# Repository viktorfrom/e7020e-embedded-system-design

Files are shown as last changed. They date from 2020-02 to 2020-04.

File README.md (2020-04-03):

# E7020E Embedded System Design
Project designed and written in Rust in conjunction with the E7020E Embedded System Design course at Luleå University of Technology. 



## Project description
The purpose of this project is to create a breathalyzer to estimate the blood alchohol content (BAC) in a person's breath. 
To do this a prototype PCB will be designed connected to an alchohol sensor, a button to start the breathalyzer and a small display to show the alchohol permille detected. Over LoRa this device will also alert a ThinkBoard server that this user's breath contains too much alchohol, i.e. they are about to pass out. 

The goal is to package this is in a simple and safe to use way for users to interact with. The data that is sent to the ThinkBoard server could be seen as sensitive data and would be ideal to encrypt it before transmitting it. 

### Limitations
There is no sure way to calibrate this device as the project team does not have access to a real industry-grade breathalyzer. Thus this device can only very roughly estimate the BAC of a person's breath and SHOULD NOT be trusted in any serious situation where it is critical to know the real BAC.

## Components / shopping list
* [Murata CMWX1ZZABZ-078](https://www.digikey.com/product-detail/en/murata-electronics/CMWX1ZZABZ-078/490-16143-1-ND/6834151)
* [Grove - Alchohol sensor](https://www.elfa.se/en/grove-alcohol-sensor-seeed-studio-101020044/p/30069826)
* [4-pin connector to sensor](https://www.elfa.se/en/grove-universal-pin-connector-seeed-studio-110990030-10pcs-pack/p/30069939)
* [SSD1306 based display](https://cdon.se/hem-tradgard/oled-display-0-96-tum-vit-128x64-pixlar-ssd1306-spi-p50506639)
* [65100516121 USB mini-B](https://www.elfa.se/en/socket-horizontal-mini-usb-smd-wuerth-elektronik-65100516121/p/14257103)
* [Pin headers](https://www.elfa.se/en/wr-phd-straight-male-pcb-header-through-hole-54mm-wuerth-elektronik-61300611121/p/30024526)
* [LM1117IMP-ADJ voltage regulator](https://www.elfa.se/en/ldo-voltage-regulator-800ma-sot-223-texas-instruments-lm1117imp-adj-nopb/p/30019193)
* [2x Electrolytic capacitors 10uF](https://www.elfa.se/en/aluminium-electrolytic-capacitor-10-uf-50-20-vs-panasonic-eee1ha100wr/p/30108011)
* [2x Buttons](https://www.elfa.se/en/print-key-50-ma-12-vdc-te-connectivity-1437565/p/13566525)
* [1x Piezo buzzer](https://www.elfa.se/en/piezo-buzzer-70-db-khz-15-murata-pkm13epyh4000-a0/p/13787082)
* [1x Antenna](https://www.elfa.se/en/micro-coaxial-straight-socket-micro-coaxial-connector-50ohm-6ghz-molex-73412-0110/p/30076410)

## Requirements
* Rustup 1.14.0+
* rustc 1.31.0+ (stable)
* GNU ARM embedded toolchain (check your package manager or manually install it)
* OpenOCD
* Nucleo dev board (in programming mode)
* Breathalyzer PCB

## Setup

### rustc & cargo
Install rustup by following the instructions at https://rustup.rs.

Then install the following tools for rustup and cargo:
```
rustup component add llvm-tools-preview
```
```
rustup target add thumbv6m-none-eabi
```
```
cargo install cargo-binutils
```

### Linux
Below are the absolute minimum packages you will need for Linux. Names might vary depending on your distribution, you might need to install it manually if you can't find it using your distribution's package manager.
```
openocd
arm-none-eabi-gdb
gcc / gcc-c++ (as well as their respective dev packages)
llvm-8.0 (and its dev package)
```

### MacOS
All the tools can be install using Homebrew:
```
brew cask install gcc-arm-embedded

brew install openocd
```
## PCB
The design of the breathalyzer can be found in _/pcbdesign_. It was created and can be opened with KiCad. The program has been written especially for that design.

## Build instructions
First confirm that the correct runner is chosen in _.cargo/config_, as the gdb package name might be different depending on you OS. Then build the project
```
cargo build --features="radio"
```

### Flashing
Connect to the card using the Nucleo F401RE dev board as a programmer with the given configuration
```
openocd -f openocd.cfg
```
Then build the project and flash the card
```
cargo run --features="radio" --release
```

## Authors
* Viktor From - vikfro-6@student.ltu.se - [viktorfrom](https://github.com/viktorfrom)
* Mark Hakansson - marhak-6@student.ltu.se - [markhakansson](https://github.com/markhakansson)
* Kyle Drysdale - kyldry-5@student.ltu.se  - [KyleLouisDrysdale](https://github.com/KyleLouisDrysdale)

## License
Licensed under the MIT license. See [LICENSE](LICENSE) for details.

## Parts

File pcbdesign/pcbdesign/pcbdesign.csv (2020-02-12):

Id | Designator | Package | Quantity | Designation | Supplier and ref
1 | G*** | BEER_SMALL | 1 | LOGO
2 | C11,C8 | C_0805_2012Metric | 2 | 10u
3 | Breathalizer1 | PinHeader_1x04_P2.54mm_Vertical | 1 | Conn_01x04_Male
4 | BZ1 | PKM13EPYH4000_piezo | 1 | Buzzer
5 | C1,C13,C15,C16,C19 | C_0805_2012Metric | 5 | 100n
6 | C7,C9,C12,C2 | C_0805_2012Metric | 4 | 0.1u
7 | C10 | C_0805_2012Metric | 1 | 1u
8 | C14,C17 | CP_Elec_5x5.3 | 2 | 10u
9 | C20 | C_0805_2012Metric | 1 | 10n
10 | J1 | PinHeader_1x06_P2.54mm_Vertical | 1 | Conn_01x06_Male
11 | J3 | U.FL_Molex_MCRF_73412-0110_Vertical | 1 | Conn_Coaxial
12 | L1 | L_0805_2012Metric | 1 | 100n
13 | R2,R4 | R_0805_2012Metric | 2 | 680
14 | R3,R5 | R_0805_2012Metric | 2 | 1200
15 | R6 | R_0805_2012Metric | 1 | 100
16 | SSD1306-SPI1 | PinHeader_1x07_P2.54mm_Vertical | 1 | Conn_01x07_Male
17 | SW1,SW2 | SW_Push_1P1T_NO_6x6mm_H9.5mm | 2 | SW_Push
18 | U1 | CMWX1ZZABZ_longer_pads | 1 | CMWX1ZZABZ-078
19 | U2 | SOT-223 | 1 | LM1117ADJ
20 | J2 | USB_Micro-B_Wuerth_629105150521 | 1 | USB_B_Micro

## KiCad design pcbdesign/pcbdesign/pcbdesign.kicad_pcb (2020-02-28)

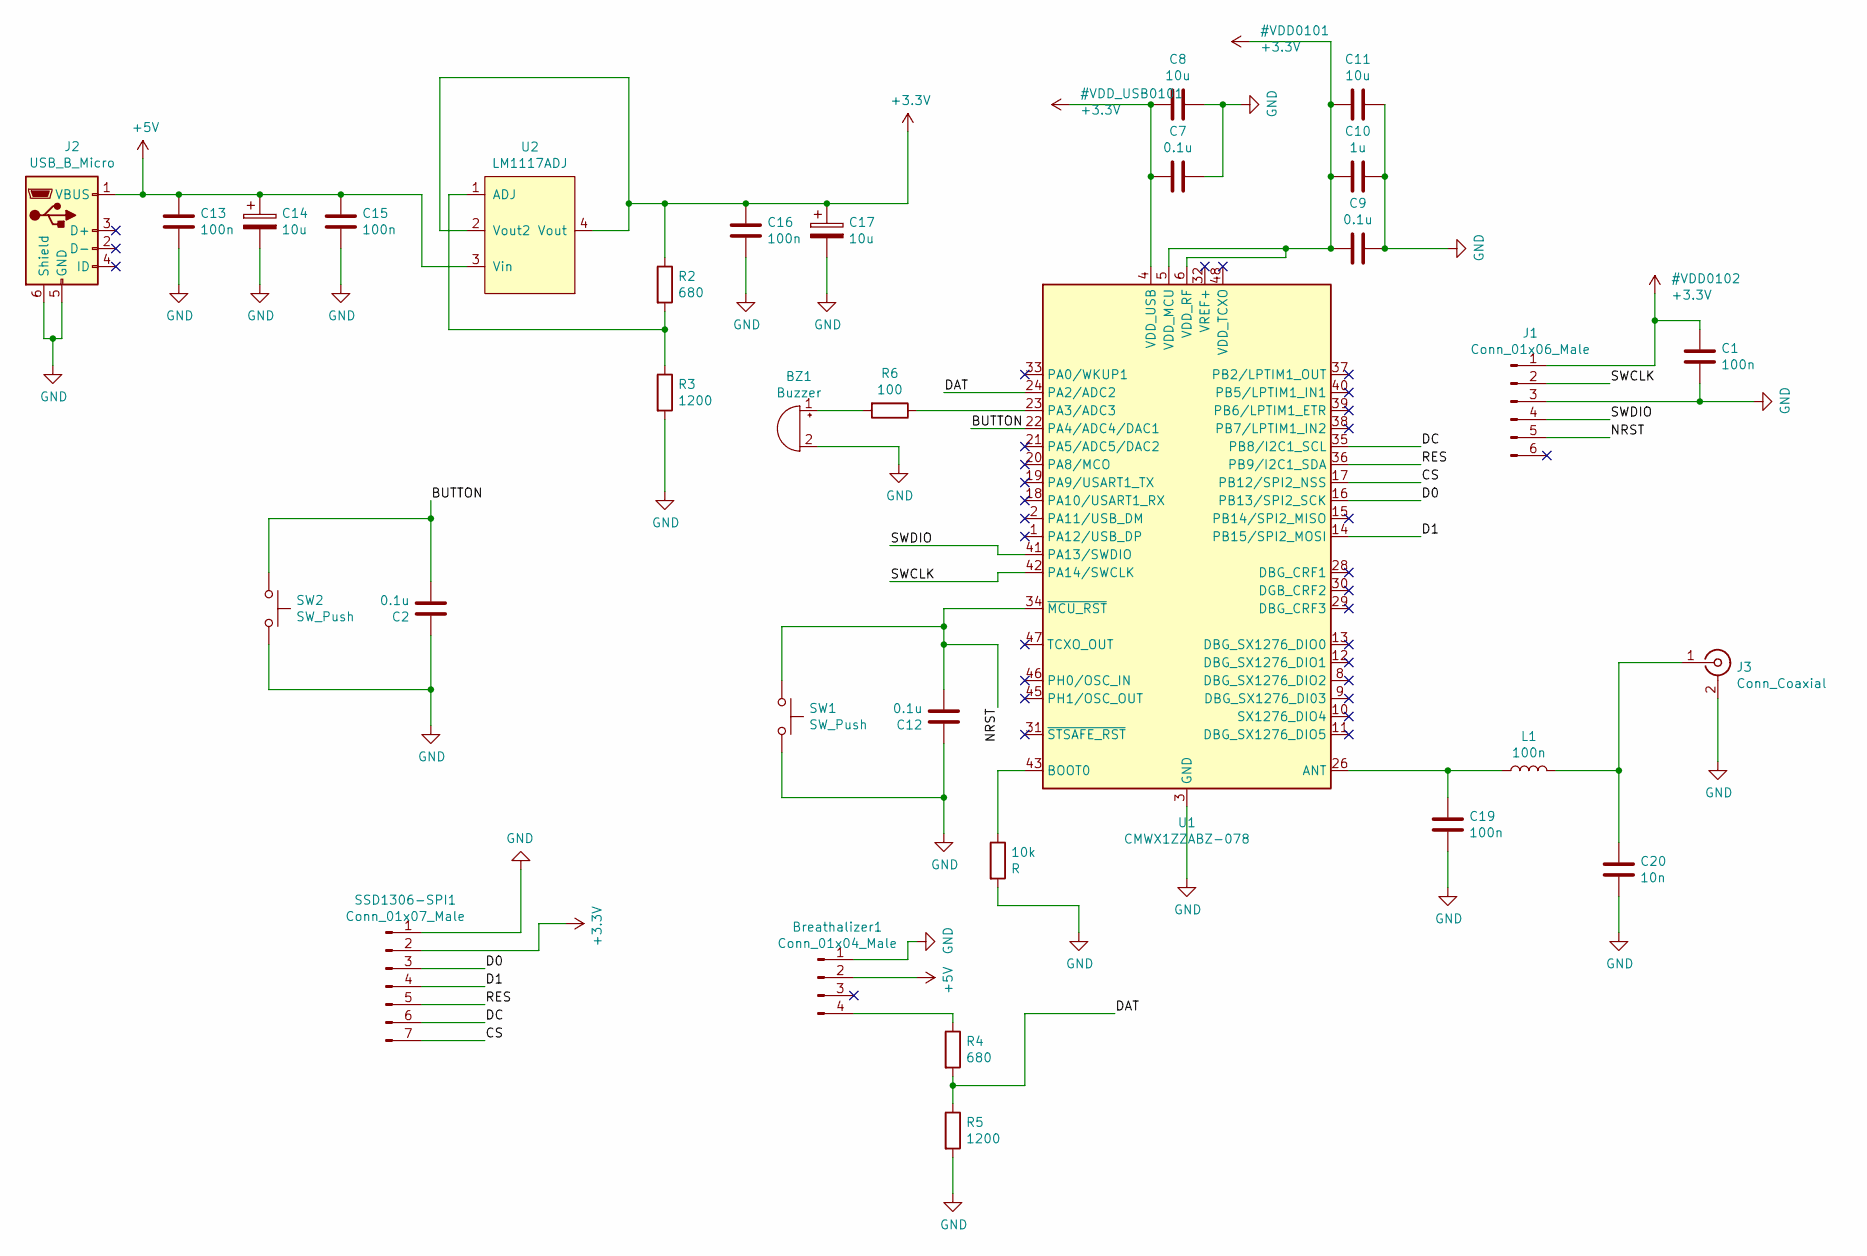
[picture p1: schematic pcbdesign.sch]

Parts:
10k: R
BZ1: Buzzer; PKM13EPYH4000_piezo
Breathalizer1: Conn_01x04_Male; PinHeader_1x04_P2.54mm_Vertical
C1, C13, C15, C16, C19: 100n; C_0805_2012Metric
C2, C7, C9, C12: 0.1u; C_0805_2012Metric
C8, C11: 10u; C_0805_2012Metric
C10: 1u; C_0805_2012Metric
C14, C17: 10u; CP_Elec_5x5.3
C20: 10n; C_0805_2012Metric
J1: Conn_01x06_Male; PinHeader_1x06_P2.54mm_Vertical
J2: USB_B_Micro; USB_Micro-B_Wuerth_629105150521
J3: Conn_Coaxial; U.FL_Molex_MCRF_73412-0110_Vertical
L1: 100n; L_0805_2012Metric
R2, R4: 680; R_0805_2012Metric
R3, R5: 1200; R_0805_2012Metric
R6: 100; R_0805_2012Metric
SSD1306-SPI1: Conn_01x07_Male; PinHeader_1x07_P2.54mm_Vertical
SW1, SW2: SW_Push; SW_Push_1P1T_NO_6x6mm_H9.5mm
U1: CMWX1ZZABZ-078; CMWX1ZZABZ_longer_pads
U2: LM1117ADJ; SOT-223

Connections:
+3V3: C1.1, C7.1, C8.1, C9.1, C10.1, C11.1, C16.1, C17.1, J1.1, R2.1, SSD1306-SPI1.2, U1.4 (VDD_USB), U1.5 (VDD_MCU), U1.6 (VDD_RF), U2.2 (Vout2), U2.4 (Vout)
+5V: Breathalizer1.2, C13.1, C14.1, C15.1, J2.1 (VBUS), U2.3 (Vin)
/BUTTON: C2.2, SW2.1, U1.22 (PA4/ADC4/DAC1)
/CS: SSD1306-SPI1.7, U1.17 (PB12/SPI2_NSS)
/D0: SSD1306-SPI1.3, U1.16 (PB13/SPI2_SCK)
/D1: SSD1306-SPI1.4, U1.14 (PB15/SPI2_MOSI)
/DAT: R4.2, R5.1, U1.24 (PA2/ADC2)
/DC: SSD1306-SPI1.6, U1.35 (PB8/I2C1_SCL)
/NRST: C12.2, J1.5, SW1.1, U1.34 (~MCU_RST)
/RES: SSD1306-SPI1.5, U1.36 (PB9/I2C1_SDA)
/SWCLK: J1.2, U1.42 (PA14/SWCLK)
/SWDIO: J1.4, U1.41 (PA13/SWDIO)
GND: 10k.2, BZ1.2 (+), Breathalizer1.1, C1.2, C2.1, C7.2, C8.2, C9.2, C10.2, C11.2, C12.1, C13.2, C14.2, C15.2, C16.2, C17.2, C19.2, C20.2, J1.3, J2.5 (GND), J2.6 (Shield), J3.2 (Ext), R3.2, R5.2, SSD1306-SPI1.1, SW1.2, SW2.2, U1.3 (GND), U1.7 (GND), U1.25 (GND), U1.27 (GND), U1.44 (GND), U1.49 (GND), U1.50 (GND), U1.51 (GND), U1.52 (GND), U1.53 (GND), U1.54 (GND), U1.55 (GND), U1.56 (GND), U1.57 (GND)
unnamed: BZ1.1 (-), R6.2
unnamed: Breathalizer1.4, R4.1
unnamed: C19.1, L1.1, U1.26 (ANT)
unnamed: C20.1, J3.1 (In), L1.2
unnamed: R2.2, R3.1, U2.1 (ADJ)
unnamed: R6.1, U1.23 (PA3/ADC3)
unnamed: 10k.1, U1.43 (BOOT0)

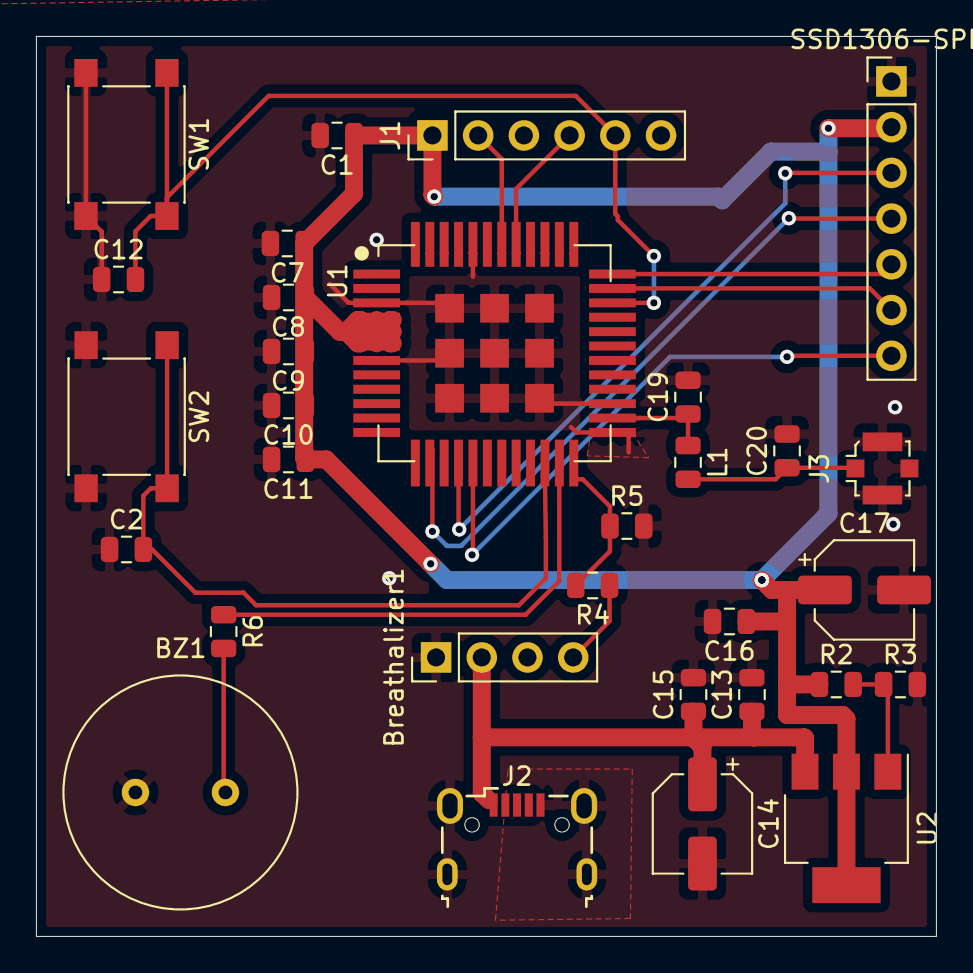
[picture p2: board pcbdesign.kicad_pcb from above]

Board: 2 copper layers, 50.0 x 50.0 mm, 31 parts (0 on the bottom side), 19 nets.

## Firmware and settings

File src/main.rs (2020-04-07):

//#![cfg_attr(not(test), no_std)]
#![no_main]
#![no_std]

mod breathalyzer;
mod buzzer;
mod longfi_bindings;
mod oled;

use longfi_bindings::AntennaSwitches;
use longfi_device::{self, ClientEvent, LongFi, RfConfig, RfEvent};
use communicator::{Message, Channel};
use heapless::consts::*;
use core::str::from_utf8;

use crate::breathalyzer::{Breathalyzer, BAC};
use crate::buzzer::Buzzer;
use crate::oled::Oled;

use stm32l0xx_hal as hal;

//#[cfg(not(debug_assertions))]
//use panic_halt as _;

// Debug imports
#[cfg(debug_assertions)]
extern crate panic_semihosting;
#[cfg(debug_assertions)]
use cortex_m_semihosting::hprintln;


use stm32l0xx_hal::{
    adc,
    delay::Delay,
    exti::TriggerEdge,
    gpio::*,
    pac,
    prelude::*,
    rcc::Config,
    spi::{self, Mode, NoMiso, Phase, Polarity},
    syscfg, 
    timer,
};

#[rtfm::app(device = stm32l0xx_hal::pac, peripherals = true)]
const APP: () = {
    struct Resources {
        #[init([0; 512])]
        BUFFER: [u8; 512], 
        #[init(0)]
        COUNT: u16,
        #[init(false)]
        BUZZER_ON: bool,
        #[init(false)]
        MEASURING: bool,
        #[init(0)]
        TIME_COUNTER: u16,
        #[init(true)]
        WARM_UP: bool,

        EXT: pac::EXTI,
        BUTTON: gpiob::PB2<Input<PullUp>>,
        TIMER_BREATH: timer::Timer<pac::TIM2>,
        TIMER_PWM: timer::Timer<pac::TIM3>,
        TIMER_SEC: timer::Timer<pac::TIM21>,
        TIMER_WARM_UP: timer::Timer<pac::TIM22>,
        BREATHALYZER: Breathalyzer,
        BUZZER: Buzzer,
        LONGFI: LongFi,
        RADIO_EXTI: gpiob::PB4<Input<PullUp>>,
        OLED: Oled,
    }

    #[init(resources = [BUFFER])]
    fn init(cx: init::Context) -> init::LateResources {
        // Configure the clock.
        let mut rcc = cx.device.RCC.freeze(Config::hsi16());
        let mut syscfg = syscfg::SYSCFG::new(cx.device.SYSCFG, &mut rcc);

        // Configure ADC
        let mut adc = adc::Adc::new(cx.device.ADC, &mut rcc);

        // Acquire the GPIOB peripheral. This also enables the clock for GPIOB in
        // the RCC register.
        let gpioa = cx.device.GPIOA.split(&mut rcc);
        let gpiob = cx.device.GPIOB.split(&mut rcc);
        let gpioc = cx.device.GPIOC.split(&mut rcc);

        // Configure inputs
        let button = gpiob.pb2.into_pull_up_input();
        let radio_int = gpiob.pb4.into_pull_up_input();

        // Configure timers
        let mut tim2 = timer::Timer::tim2(cx.device.TIM2, 1000.ms(), &mut rcc);
        let mut tim3 = timer::Timer::tim3(cx.device.TIM3, 1000.hz(), &mut rcc);
        let mut tim21 = timer::Timer::tim21(cx.device.TIM21, 1000.ms(), &mut rcc);
        let mut tim22 = timer::Timer::tim22(cx.device.TIM22, 1000.ms(), &mut rcc);

        // External interrupt
        let exti = cx.device.EXTI;

        // Configure interrupts
        exti.listen(
            &mut syscfg,
            radio_int.port(),
            radio_int.pin_number(),
            TriggerEdge::Rising,
        );

        exti.listen(
            &mut syscfg,
            button.port(),
            button.pin_number(),
            TriggerEdge::Falling,
        );

        tim2.listen();
        tim3.listen();
        tim21.listen();
        tim22.listen();

        // Initialize radio.
        let radio_sck = gpiob.pb3;
        let radio_miso = gpioa.pa6;
        let radio_mosi = gpioa.pa7;
        let radio_nss = gpioa.pa15.into_push_pull_output();
        longfi_bindings::set_spi_nss(radio_nss);

        let mut spi1 = cx.device
            .SPI1
            .spi((radio_sck, radio_miso, radio_mosi), spi::MODE_0, 1_000_000.hz(), &mut rcc);

        let radio_reset = gpioc.pc0.into_push_pull_output();
        longfi_bindings::set_radio_reset(radio_reset);
    
        let ant_sw = AntennaSwitches::new(
            gpioa.pa1.into_push_pull_output(),
            gpioc.pc2.into_push_pull_output(),
            gpioc.pc1.into_push_pull_output(),
        );

        longfi_bindings::set_antenna_switch(ant_sw);

        let en_tcxo = gpiob.pb5.into_push_pull_output();
        longfi_bindings::set_tcxo_pins(en_tcxo);

        static mut BINDINGS: longfi_device::BoardBindings = longfi_device::BoardBindings {
            reset: Some(longfi_bindings::radio_reset),
            spi_in_out: Some(longfi_bindings::spi_in_out),
            spi_nss: Some(longfi_bindings::spi_nss),
            delay_ms: Some(longfi_bindings::delay_ms),
            get_random_bits: Some(longfi_bindings::get_random_bits),
            set_antenna_pins: Some(longfi_bindings::set_antenna_pins),
            set_board_tcxo: Some(longfi_bindings::set_tcxo),
        };

        let rf_config = RfConfig {
            oui: 0xBEEF_FEED,
            device_id: 0xABCD,
        };

        let mut longfi_radio = unsafe { LongFi::new(&mut BINDINGS, rf_config).unwrap() };

        longfi_radio.set_buffer(cx.resources.BUFFER);

        longfi_radio.receive();

        // Initialize OLED
        let mut cs = gpiob.pb12.into_push_pull_output();
        cs.set_low().unwrap(); // not sure if needed, did not try without it

        let sck = gpiob.pb13;
        let mosi = gpiob.pb15;
        let mut delay = Delay::new(cx.core.SYST, rcc.clocks);

        // Initialise the SPI peripheral.
        let mut spi =
            cx.device
                .SPI2
                .spi((sck, NoMiso, mosi), spi::MODE_0, 1_000_000.hz(), &mut rcc);

        // Initialize modules
        let mut buzzer = Buzzer::new(gpioa.pa3);
        let mut breathalyzer = Breathalyzer::new(gpioa.pa5, gpioa.pa2, adc);
        breathalyzer.on();
        let mut oled = Oled::new(spi, gpiob.pb8, gpiob.pb9, delay);

        let test: f32 = 0.5;

        // Return the initialised resources.
        init::LateResources {
            EXT: exti,
            BUTTON: button,
            TIMER_BREATH: tim2,
            TIMER_PWM: tim3,
            TIMER_SEC: tim21,
            TIMER_WARM_UP: tim22,
            BREATHALYZER: breathalyzer,
            BUZZER: buzzer,
            LONGFI: longfi_radio,
            RADIO_EXTI: radio_int,
            OLED: oled,
        }
    }

    // External interrupt for the button
    #[task(binds = EXTI2_3, priority = 2, spawn = [button_event], resources = [EXT, BUTTON, WARM_UP])]
    fn exti2_3(cx: exti2_3::Context) {
        //hprintln!("exti2_3").unwrap();
        cx.resources.EXT.clear_irq(cx.resources.BUTTON.pin_number());

        if !*cx.resources.WARM_UP {
            cx.spawn.button_event().unwrap();
        }
    }

    // External interrupt for the radio
    #[task(binds = EXTI4_15, priority = 2, spawn = [radio_event], resources = [EXT, RADIO_EXTI, WARM_UP])]
    fn exti4_15(cx: exti4_15::Context) {
        //hprintln!("exti4_15").unwrap();
        cx.resources.EXT.clear_irq(cx.resources.RADIO_EXTI.pin_number());

        if !*cx.resources.WARM_UP {
            cx.spawn.radio_event(RfEvent::DIO0).unwrap();
        }
    }

    #[task(capacity = 4, priority = 2, spawn = [button_event], resources = [BUFFER, LONGFI])]
    fn radio_event(cx: radio_event::Context, event: RfEvent) {
        let mut longfi_radio = cx.resources.LONGFI;
        let client_event = longfi_radio.handle_event(event);

        match client_event {
            ClientEvent::ClientEvent_TxDone => {
                longfi_radio.receive();
            },
            ClientEvent::ClientEvent_Rx => {
                let rx_packet = longfi_radio.get_rx();

                {
                    let buf = unsafe {
                        core::slice::from_raw_parts(rx_packet.buf, rx_packet.len as usize)
                    };

                    let message = Message::deserialize(buf);

                    if let Some(message) = message {
                        // Let's assume we only have permission to use ID 6:
                        if message.id == 6 {
                            cx.spawn.button_event().unwrap();
                        }
                    }
                }

                longfi_radio.set_buffer(cx.resources.BUFFER);
                longfi_radio.receive();
            }
            ClientEvent::ClientEvent_None => {}
        }
    }

    #[task(priority = 2, resources = [LONGFI])]
    fn send_radio_message(cx: send_radio_message::Context, bac: BAC) {
        let bac_convert = match bac {
            BAC::NONE => 0,
            BAC::LOW => 1,
            BAC::MEDIUM => 2,
            BAC::HIGH => 3,
            BAC::VERY_HIGH => 4,
            BAC::DEATH => 5
        };

        // Wrap the message in a way such that ThingsBoard can handle it
        let message = Message {
            id: 6,
            data: bac_convert,
            channel: Channel::One
        };
    
        let binary = Message::serialize(&message).unwrap();
        cx.resources.LONGFI.send(&binary);
    }

    // Handles the button press
    #[task(priority = 2, spawn = [send_radio_message], resources = [BUTTON, BUZZER, BREATHALYZER, OLED, MEASURING, TIMER_SEC])]
    fn button_event(cx: button_event::Context) {
        if !*cx.resources.MEASURING {
            if cx.resources.BUZZER.enabled {
                cx.resources.BUZZER.disable();
                let mut value: BAC = cx.resources.BREATHALYZER.read();

                let val = match value {
                    BAC::NONE => "NONE",
                    BAC::LOW => "LOW",
                    BAC::MEDIUM => "MEDIUM",
                    BAC::HIGH => "HIGH",
                    BAC::VERY_HIGH => "VERY HIGH",
                    BAC::DEATH => "DEATH"
                };
                cx.resources.OLED.on(val);

                // Send radio message, place this wherever it is needed
                cx.spawn.send_radio_message(value).unwrap();
            } else {
                cx.resources.OLED.on("Reading");
                // constant beep
                cx.resources.BUZZER.enable();
                cx.resources.TIMER_SEC.listen();
                *cx.resources.MEASURING = true;
            }
        }
    }

    // Polls the alcohol sensor
    #[task(binds = TIM2, priority = 2, resources = [TIMER_BREATH, BREATHALYZER])]
    fn sensor_poll(mut cx: sensor_poll::Context) {
        cx.resources.TIMER_BREATH.clear_irq();
        let val = cx.resources.BREATHALYZER.read_curr();

        if !(val < cx.resources.BREATHALYZER.curr_val) {
            cx.resources.BREATHALYZER.curr_val = cx.resources.BREATHALYZER.read_curr();
        }
    }

    // Toggles the buzzer's PWM according to the set frequency
    #[task(binds = TIM3, priority = 2, resources = [BUZZER, TIMER_PWM])]
    fn buzzer_pwm(mut cx: buzzer_pwm::Context) {
        cx.resources.TIMER_PWM.clear_irq();
        cx.resources.BUZZER.toggle_pwm();
    }

    #[task(binds = TIM21, spawn = [button_event], resources = [BUZZER, TIME_COUNTER, TIMER_SEC, MEASURING])]
    fn stop_measuring(mut cx: stop_measuring::Context) {
        cx.resources.TIMER_SEC.lock(|TIMER_SEC| TIMER_SEC.clear_irq());
        let mut measuring: bool = cx.resources.MEASURING.lock(|MEASURING| return *MEASURING);
        let mut counter: u16 = *cx.resources.TIME_COUNTER;
        let mut complete: bool = false;

        if measuring {
            if counter >= 3 {
                cx.resources.MEASURING.lock(|MEASURING| {
                    *MEASURING = false;
                });
                complete = true;
            } else {
                counter += 1;
                *cx.resources.TIME_COUNTER = counter;
            }
        }

        if complete {
            *cx.resources.TIME_COUNTER = 0;
            cx.spawn.button_event().unwrap();
        }
    }

    // Device warm up
    #[task(binds = TIM22, priority = 2, resources = [OLED, BREATHALYZER, COUNT, TIMER_WARM_UP, WARM_UP])]
    fn warm_up(cx: warm_up::Context) {
        cx.resources.TIMER_WARM_UP.clear_irq();

        if *cx.resources.COUNT != 10 {
            cx.resources.OLED.on("Warming up");
            *cx.resources.COUNT += 1;
        } else {
            cx.resources.OLED.on("Ready");
            cx.resources.TIMER_WARM_UP.unlisten();
            *cx.resources.COUNT = 0;
            *cx.resources.WARM_UP = false;
        }
    }

    // Interrupt handlers used to dispatch software tasks
    extern "C" {
        fn USART1();
        fn USART2();
        fn USART4_USART5();
    }
};

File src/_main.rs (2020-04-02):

#![cfg_attr(not(test), no_std)]
#![no_main]
#![allow(deprecated)]

mod longfi_bindings;

extern crate panic_semihosting;

use hal::{
    exti::TriggerEdge,
    gpio::*,
    pac,
    prelude::*,
    rcc::Config,
    spi,
    syscfg,
    timer::Timer
};
use longfi_bindings::AntennaSwitches;
use longfi_device;
use longfi_device::LongFi;
use longfi_device::{ClientEvent, RfConfig, RfEvent};
use stm32l0xx_hal as hal;
use communicator::{Message, Channel};
use heapless::consts::*;

use cortex_m_semihosting::hprintln;

#[rtfm::app(device = stm32l0xx_hal::pac)]
const APP: () = {
    static mut INT: pac::EXTI = ();
    static mut SX1276_DIO0: gpiob::PB4<Input<PullUp>> = ();
    static mut BUFFER: [u8; 512] = [0; 512];
    static mut LONGFI: LongFi = ();
    static mut STATE: bool = false;
    static mut COUNTER_1: u32 = 0;
    static mut COUNTER_2: u32 = 0;

    static mut UPLINK_TIMER: Timer<pac::TIM2> = ();

    #[init(resources = [BUFFER])]
    fn init() -> init::LateResources {
        // Configure the clock.
        let mut rcc = device.RCC.freeze(Config::hsi16());
        let mut syscfg = syscfg::SYSCFG::new(device.SYSCFG, &mut rcc);

        // Acquire the GPIOB peripheral. This also enables the clock for GPIOB in
        // the RCC register.
        let gpioa = device.GPIOA.split(&mut rcc);
        let gpiob = device.GPIOB.split(&mut rcc);
        let gpioc = device.GPIOC.split(&mut rcc);

        let exti = device.EXTI;

        // Configure PB4 as input.
        let sx1276_dio0 = gpiob.pb4.into_pull_up_input();
        // Configure the external interrupt on the falling edge for the pin 2.
        exti.listen(
            &mut syscfg,
            sx1276_dio0.port(),
            sx1276_dio0.pin_number(),
            TriggerEdge::Rising,
        );

        let sck = gpiob.pb3;
        let miso = gpioa.pa6;
        let mosi = gpioa.pa7;
        let nss = gpioa.pa15.into_push_pull_output();
        longfi_bindings::set_spi_nss(nss);

        // Initialise the SPI peripheral.
        let mut _spi = device
            .SPI1
            .spi((sck, miso, mosi), spi::MODE_0, 1_000_000.hz(), &mut rcc);

        let reset = gpioc.pc0.into_push_pull_output();
        longfi_bindings::set_radio_reset(reset);

        let ant_sw = AntennaSwitches::new(
            gpioa.pa1.into_push_pull_output(),
            gpioc.pc2.into_push_pull_output(),
            gpioc.pc1.into_push_pull_output(),
        );

        longfi_bindings::set_antenna_switch(ant_sw);

        let en_tcxo = gpiob.pb5.into_push_pull_output();
        longfi_bindings::set_tcxo_pins(en_tcxo);

        static mut BINDINGS: longfi_device::BoardBindings = longfi_device::BoardBindings {
            reset: Some(longfi_bindings::radio_reset),
            spi_in_out: Some(longfi_bindings::spi_in_out),
            spi_nss: Some(longfi_bindings::spi_nss),
            delay_ms: Some(longfi_bindings::delay_ms),
            get_random_bits: Some(longfi_bindings::get_random_bits),
            set_antenna_pins: Some(longfi_bindings::set_antenna_pins),
            set_board_tcxo: Some(longfi_bindings::set_tcxo),
        };

        let rf_config = RfConfig {
            oui: 0xBEEF_FEED,
            device_id: 0xABCD,
        };

        let mut longfi_radio = unsafe { LongFi::new(&mut BINDINGS, rf_config).unwrap() };

        longfi_radio.set_buffer(resources.BUFFER);

        longfi_radio.receive();

        let mut uplink_timer = device.TIM2.timer(1.hz(), &mut rcc);
        //uplink_timer.listen();

        // Return the initialised resources.
        init::LateResources {
            INT: exti,
            SX1276_DIO0: sx1276_dio0,
            LONGFI: longfi_radio,
            UPLINK_TIMER: uplink_timer
        }
    }

    #[task(capacity = 4, priority = 2, resources = [BUFFER, LONGFI, STATE, COUNTER_1, COUNTER_2])]
    fn radio_event(event: RfEvent) {
        let mut longfi_radio = resources.LONGFI;
        let client_event = longfi_radio.handle_event(event);
        match client_event {
            ClientEvent::ClientEvent_TxDone => {
                hprintln!("transmission done").unwrap();
                longfi_radio.receive();
            }
            ClientEvent::ClientEvent_Rx => {
                let rx_packet = longfi_radio.get_rx();

                {
                    let buf = unsafe {
                        core::slice::from_raw_parts(rx_packet.buf, rx_packet.len as usize)
                    };

                    hprintln!("rx len {}", rx_packet.len).unwrap();

                    hprintln!("before").unwrap();
                    let message = Message::deserialize(buf);
                    
                    if let Some(message) = message {
                        hprintln!("parse").unwrap();
                        // Let's assume we only have permission to use ID 2:
                        if message.id != 2 {
                            longfi_radio.set_buffer(resources.BUFFER);
                            longfi_radio.receive();
                            hprintln!("wrong address").unwrap();
                            return;
                        }

                        hprintln!("sending message").unwrap();
                        let binary = application(
                            message,
                            resources.COUNTER_1,
                            resources.COUNTER_2,
                            resources.STATE,
                        );
                        longfi_radio.send(&binary);
                    }
                }

                longfi_radio.set_buffer(resources.BUFFER);
                longfi_radio.receive();
            }
            ClientEvent::ClientEvent_None => {}
        }
    }

    #[interrupt(priority = 1, resources = [SX1276_DIO0, INT], spawn = [radio_event])]
    fn EXTI4_15() {
        resources.INT.clear_irq(resources.SX1276_DIO0.pin_number());
        spawn.radio_event(RfEvent::DIO0).unwrap();
    }

    // This should not be a separate task from TIM2
    #[task(capacity = 4, priority = 2, resources = [LONGFI])]
    fn send_ping() {
        static mut STATE: bool = false;
        hprintln!("pinging...").unwrap();
        let packet: [u8; 16] = [
            0xa0, 0xa1, 0xa2, 0xa3, 0xa4, 0xa5, 0xa6, 0xa7, 0xa8, 0xa9, 0xaa, 0xab, 0xac, 0xad, 0xae, 0xaf,
        ];

        resources.LONGFI.send(&packet);
    }

    #[interrupt(resources = [UPLINK_TIMER], spawn = [send_ping])]
    fn TIM2() {
        resources.UPLINK_TIMER.clear_irq();
        spawn.send_ping().ok();
    }

    // Interrupt handlers used to dispatch software tasks
    extern "C" {
        fn USART4_USART5();
    }
};
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

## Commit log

2020-02-03 Add pcbdesign
    [pcbdesign.kicad_pcb, pcbdesign.sch]
2020-02-03 Update pcbdesign
2020-02-06 Add pull-up resistor to CS pin on SPI connector
    [pcbdesign.sch]
2020-02-10 Place components on PCB
    [pcbdesign.sch]
2020-02-11 Finish copper routing
    [pcbdesign.kicad_pcb, pcbdesign.sch]
2020-02-12 Finish review of board. Add text and logo to PCB
    [pcbdesign.csv, pcbdesign.kicad_pcb, pcbdesign.sch]
2020-02-13 Add gerber files
    [pcbdesign-B_Cu.gbr, pcbdesign-B_Mask.gbr, pcbdesign-B_SilkS.gbr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]
2020-02-17 Add configs for running the debugging tools.
    [pcbdesign.kicad_pcb, stm32f4x.cfg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]
2020-02-28 Add stm32l0.cfg
    [stm32l0.cfg]
2020-03-02 Update project to use stm32l0 and RTFM
2020-03-03 Update memory.x to use STM32l0x2 memory values
2020-03-04 Remove ITM from gdb file as there is no support for it on the STM32L0X2
2020-03-04 Add dual bank config for openocd
    [stm32l0_dual_bank.cfg]
2020-03-16 Add example for alcohol sensor
2020-03-16 Finish alcohol sensor example
2020-03-18 Add buzzer as module
    [buzzer.rs, main.rs]
2020-03-20 Update buzzer example with intervals between beeps
    [buzzer.rs]
2020-03-20 Update and add buzzer to main project
    [buzzer.rs, main.rs]
2020-03-22 Update the buzzer module to be more intuitive. Buzzer and sensor can run simultanously
    [buzzer.rs, main.rs]
2020-03-24 Add oled on button press
2020-04-01 Update PCB schematic to include the missing wires
    [pcbdesign.sch]
2020-04-01 Add wire for LoRa crystal, annotate forgotten resistor
    [pcbdesign.sch]
2020-04-02 Fix buzzer bug where the button press would be ignored sometimes
    [buzzer.rs, main.rs]
2020-04-02 Connect sensor to OLED
2020-04-03 Final STL files for breathalyzer shell.
2020-04-07 Fix task priorities. It is no longe possible to spam multiple tasks while breathalyzer is running
    [main.rs]
